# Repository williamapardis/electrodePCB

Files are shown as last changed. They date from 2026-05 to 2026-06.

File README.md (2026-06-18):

# electrodePCB
A convenient solution-circuit interface. The electrode printed circuit board (PCB) is a experimental utility with submersible application of electrochemistry in mind. The PCB is designed to fasten directly to a Blue Robotic (BR) Enclosure - [2" Cylindrical Locking Series - O-ring flanges](https://bluerobotics.com/store/watertight-enclosures/locking-series/wte-flange-vp/). The front side (or wet side) of the PCB is a layout of gold plated pads that act as substrate for unique solution processed electrode materials. The back side (or dry side) internal to the BR enclosure hosts both passive and active circuitry, their respective layout and interconnection to circuit and electrodes thought a multi. pos. FPC cable. 

<p align="center">
  
  
</p>

## rE
<p align="center">
  
  
</p>
We have upgraded to a 20 position FPC connector to accomidate more features. One these features include an additional heating element for thermal probing of the electrodes. Probing of the.

## rD
<p align="center">
  
  
</p>

## rC
<p align="center">
  
  
</p>

## rB
<p align="center">
  
  
</p>

## rA
<p align="center">
  
  
</p>

### next revision
add a convenient way to disconnect electrodes from FPC

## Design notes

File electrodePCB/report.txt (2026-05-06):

Warning: Width correction constrained.  The width correction value must be in the range of [0.000001 mm; 0.199999 mm] for the current design rules.
Plotted to '/Users/williampardis/Documents/theConductor/theConductor-F_Cu.gbr'.
Plotted to '/Users/williampardis/Documents/theConductor/theConductor-B_Cu.gbr'.
Plotted to '/Users/williampardis/Documents/theConductor/theConductor-F_Paste.gbr'.
Plotted to '/Users/williampardis/Documents/theConductor/theConductor-B_Paste.gbr'.
Plotted to '/Users/williampardis/Documents/theConductor/theConductor-F_Silkscreen.gbr'.
Plotted to '/Users/williampardis/Documents/theConductor/theConductor-B_Silkscreen.gbr'.
Plotted to '/Users/williampardis/Documents/theConductor/theConductor-F_Mask.gbr'.
Plotted to '/Users/williampardis/Documents/theConductor/theConductor-B_Mask.gbr'.
Plotted to '/Users/williampardis/Documents/theConductor/theConductor-Edge_Cuts.gbr'.
Created Gerber job file '/Users/williampardis/Documents/theConductor/theConductor-job.gbrjob'.
Plotted to '/Users/williampardis/Documents/theConductor/theConductor-F_Cu.gbr'.
Plotted to '/Users/williampardis/Documents/theConductor/theConductor-B_Cu.gbr'.
Plotted to '/Users/williampardis/Documents/theConductor/theConductor-F_Paste.gbr'.
Plotted to '/Users/williampardis/Documents/theConductor/theConductor-B_Paste.gbr'.
Plotted to '/Users/williampardis/Documents/theConductor/theConductor-F_Silkscreen.gbr'.
Plotted to '/Users/williampardis/Documents/theConductor/theConductor-B_Silkscreen.gbr'.
Plotted to '/Users/williampardis/Documents/theConductor/theConductor-F_Mask.gbr'.
Plotted to '/Users/williampardis/Documents/theConductor/theConductor-B_Mask.gbr'.
Plotted to '/Users/williampardis/Documents/theConductor/theConductor-Edge_Cuts.gbr'.
Created Gerber job file '/Users/williampardis/Documents/theConductor/theConductor-job.gbrjob'.
Info: Done.
Info: Done.

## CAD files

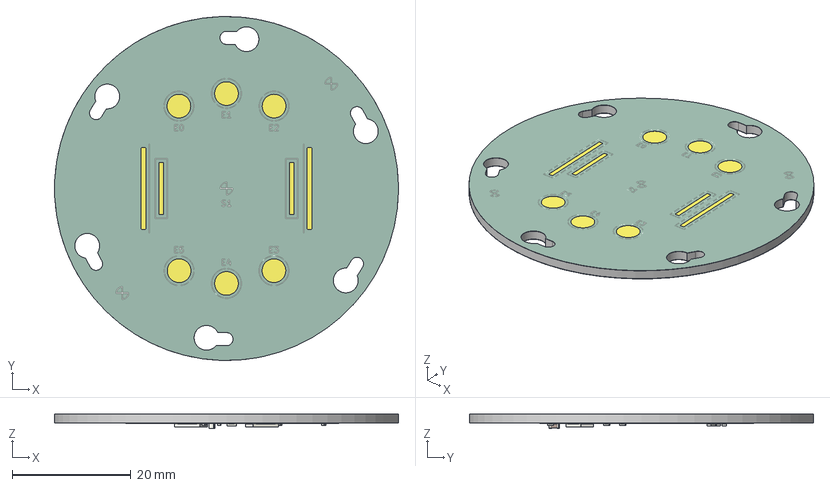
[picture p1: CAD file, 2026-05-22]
electrodePCB/electrodePCB.step
58.0 x 58.0 x 2.47 mm
R_0402_1005Metric x 4
R_0603_1608Metric x 3
R_2010_5025Metric x 2
C_0603_1608Metric
electrodePCB_copper
electrodePCB_silkscreen
electrodePCB_soldermask
electrodePCB_PCB

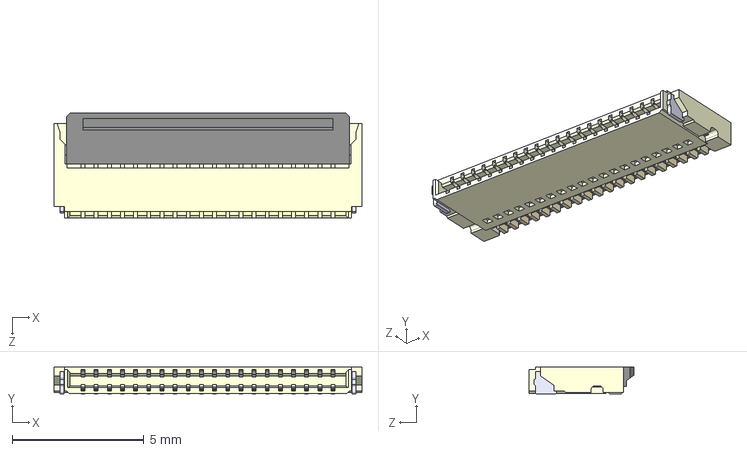
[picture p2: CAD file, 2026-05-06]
electrodePCB/FPC/5034802000.step
11.7 x 1.02 x 4.00 mm

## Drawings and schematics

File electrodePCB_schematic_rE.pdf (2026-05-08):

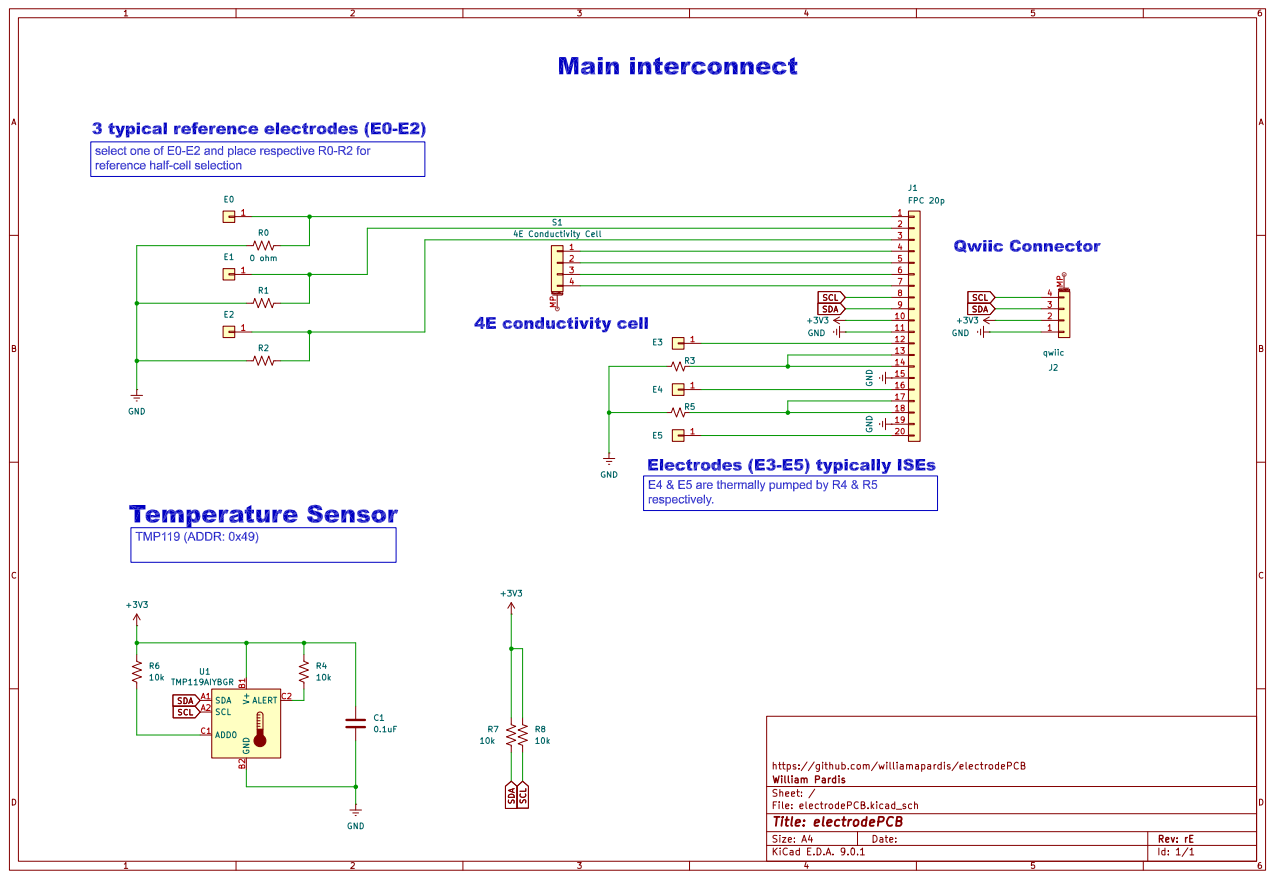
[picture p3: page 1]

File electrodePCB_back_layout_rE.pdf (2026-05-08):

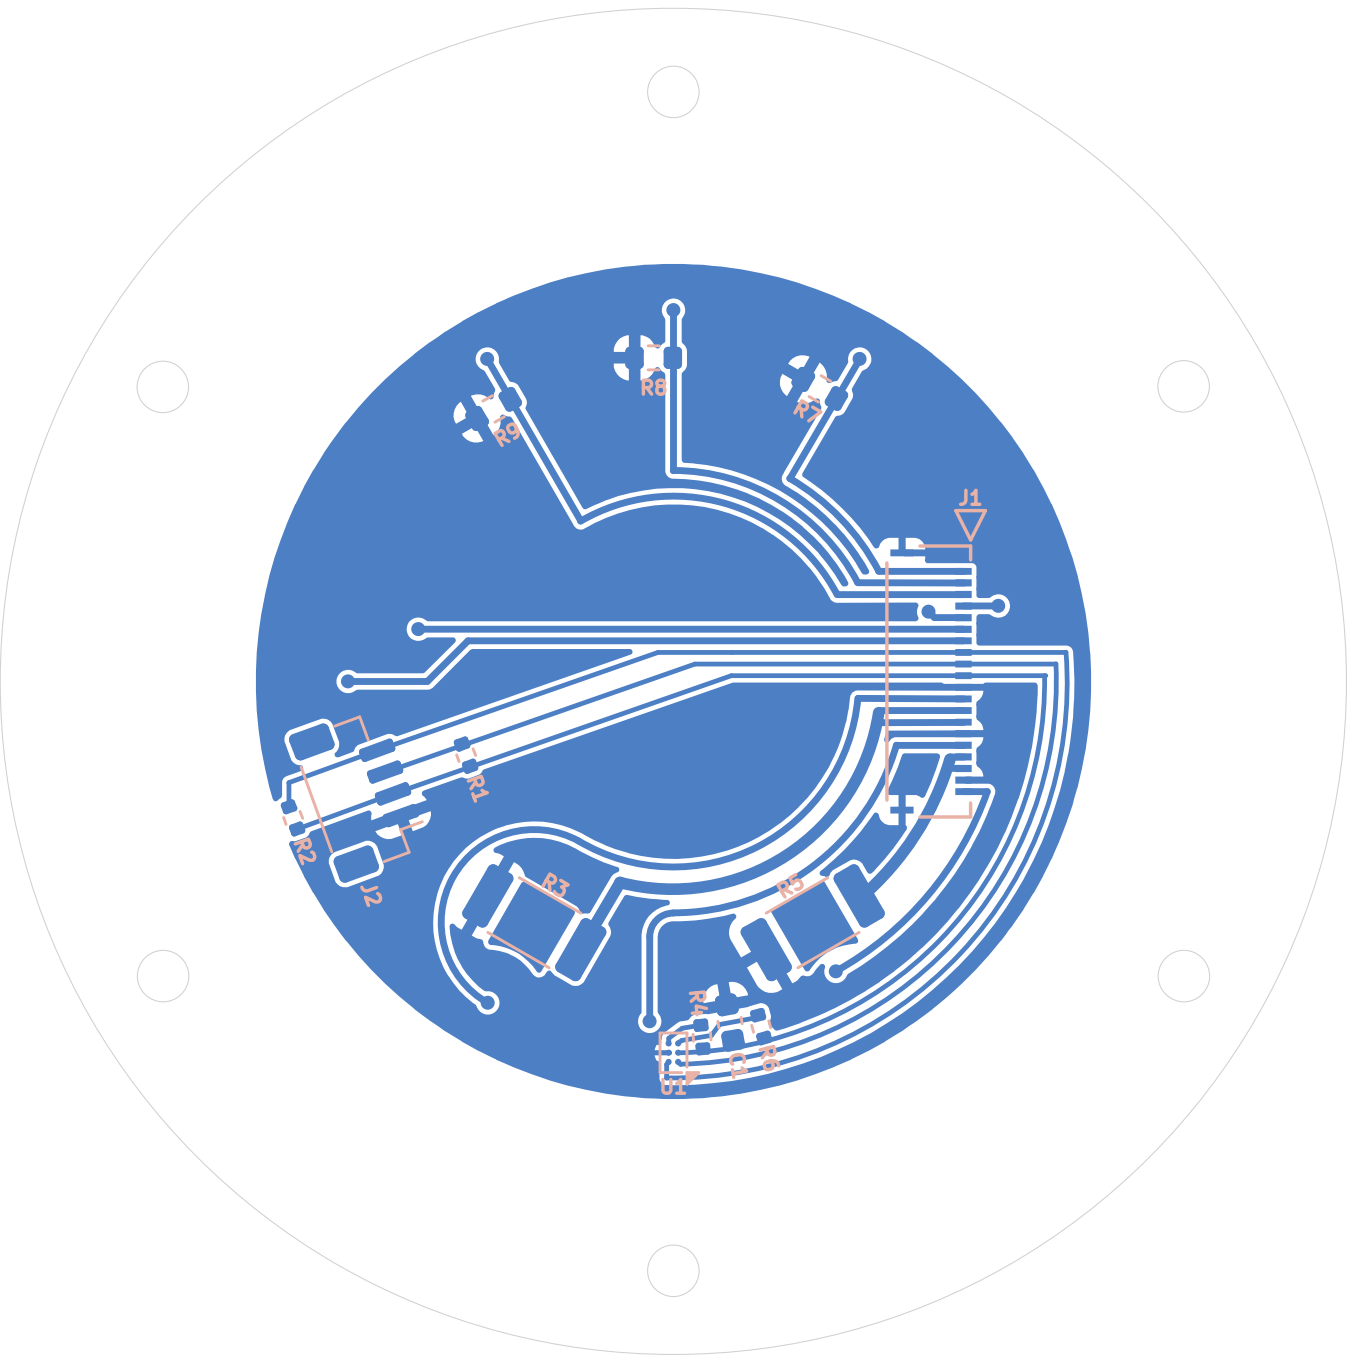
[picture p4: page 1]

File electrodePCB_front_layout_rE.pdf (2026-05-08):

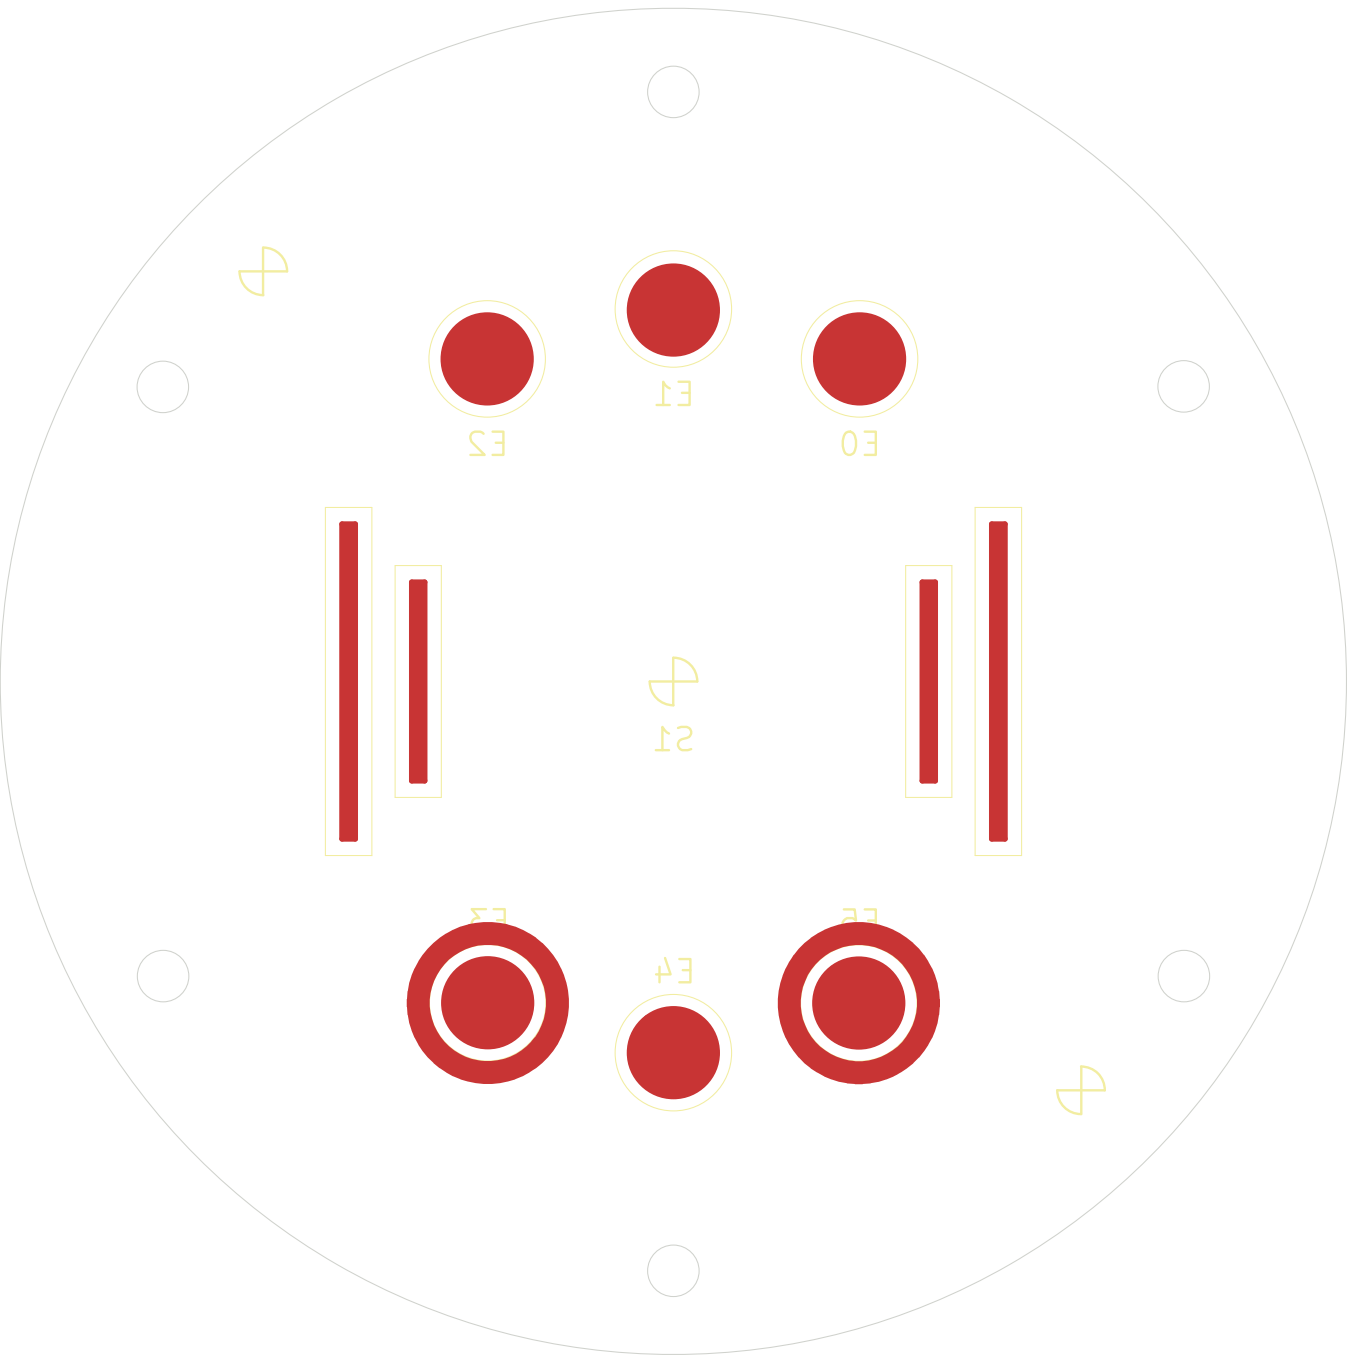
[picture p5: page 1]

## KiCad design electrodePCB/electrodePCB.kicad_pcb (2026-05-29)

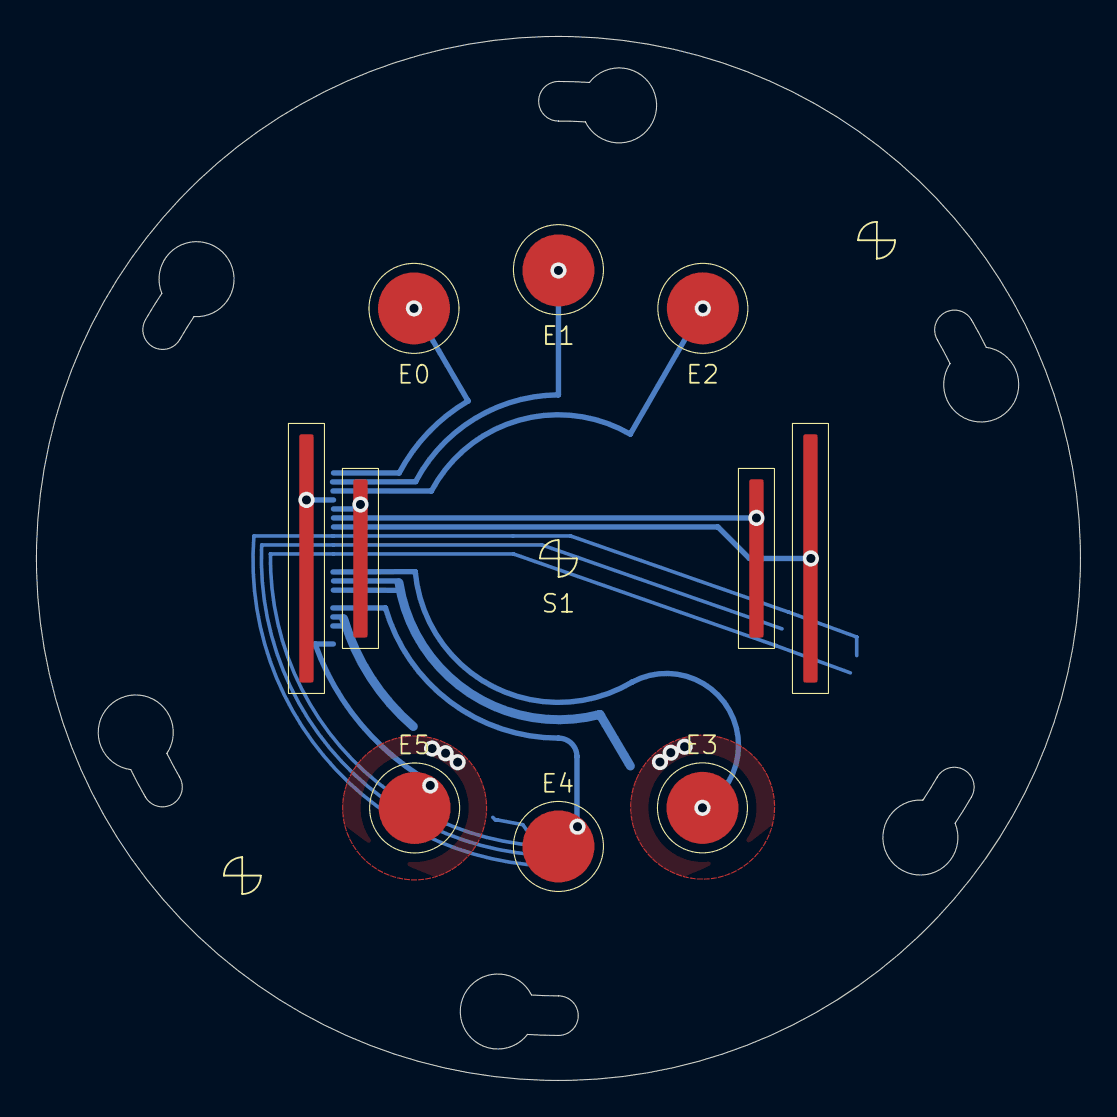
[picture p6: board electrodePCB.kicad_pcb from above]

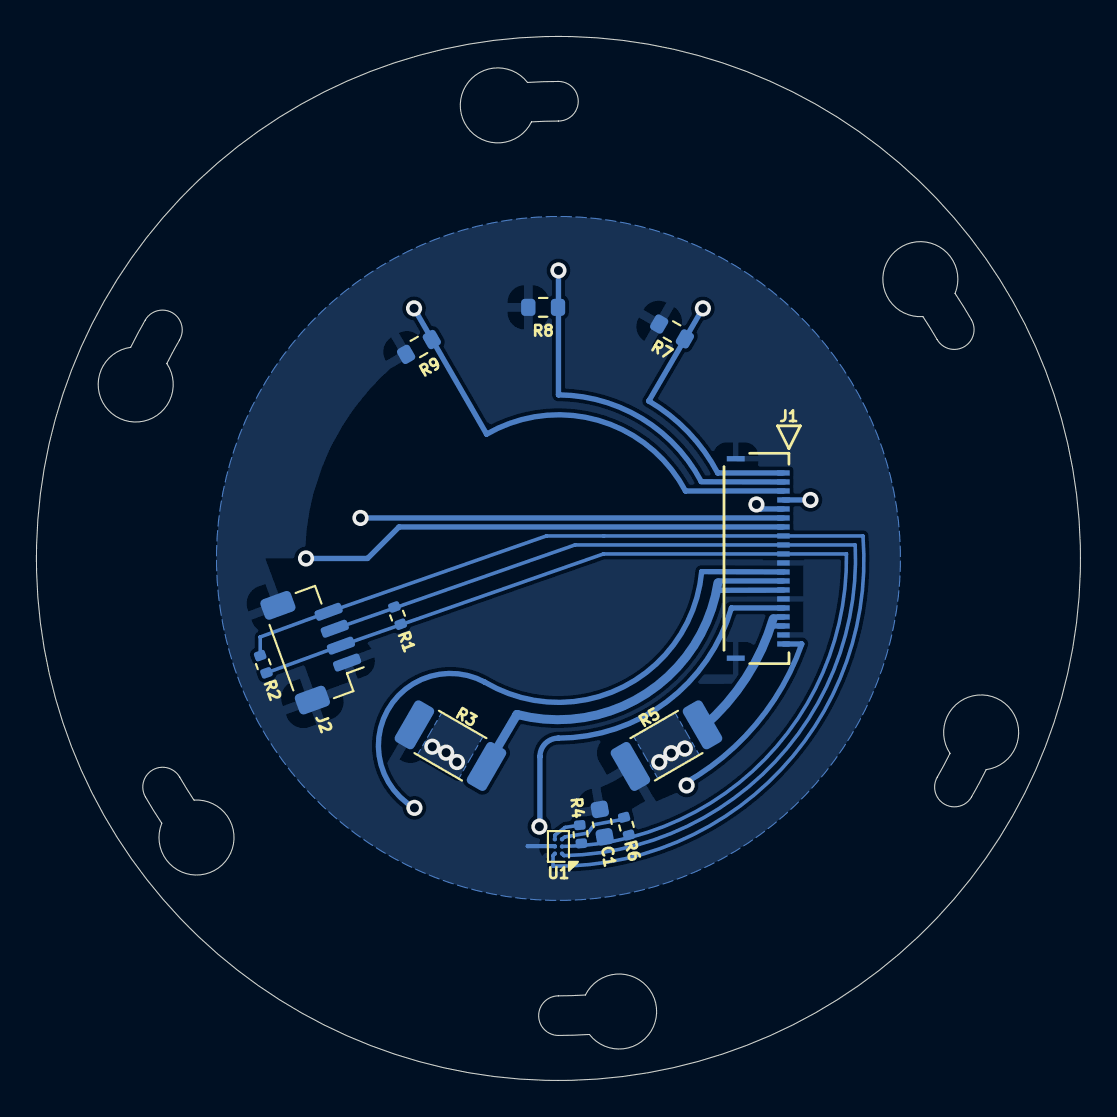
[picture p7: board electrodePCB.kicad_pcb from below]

Board: 2 copper layers, 58.0 x 58.0 mm, 20 parts (13 on the bottom side), 18 nets.

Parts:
C1: 0.1uF; C_0603_1608Metric
E0, E1, E2, E3, E4, E5: Conn_01x01; Circular_10mm
J1: FPC 20p; CON_5034802000_MOL
J2: qwiic; JST_SH_BM04B-SRSS-TB_1x04-1MP_P1.00mm_Vertical
R1, R2, R4, R6: 10k; R_0402_1005Metric
R3, R5: R_Small_US; R_2010_5025Metric
R7, R8, R9: R_US; R_0603_1608Metric
S1: 4E Conductivity Cell; Conductivity_Cell_K10
U1: TMP119AIYBGR; Texas_DSBGA-6_0.95x1.488mm_Layout2x3_P0.4mm

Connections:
+3V3: C1.1, J1.10, J2.2, R1.1, R2.2, R4.2, R6.1, U1.B1 (V+)
GND: C1.2, J1.11, J1.15, J1.19, J1.P1, J1.P2, J2.1, J2.MP (MountPin), R3.2, R5.2, R7.1, R8.1, R9.1, U1.B2 (GND)
unnamed: E0.1, J1.1, R7.2
unnamed: E1.1, J1.2, R8.2
unnamed: E2.1, J1.3, R9.2
unnamed: E3.1, J1.12
unnamed: E4.1, J1.16
unnamed: E5.1, J1.20
unnamed: J1.4, S1.1
unnamed: J1.5, S1.2
unnamed: J1.6, S1.3
unnamed: J1.7, S1.4
unnamed: J1.13, J1.14, R3.1
unnamed: J1.17, J1.18, R5.1
unnamed: R6.2, U1.C1 (ADD0)
unnamed: R4.1, U1.C2 (ALERT)
SCL: J1.8, J2.4, R2.1, U1.A2 (SCL)
SDA: J1.9, J2.3, R1.2, U1.A1 (SDA)

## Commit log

2026-05-06 adding KiCad design files and a seperate directory specifically for zip'd fab. files
    [5034802000.step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]
2026-05-06 still in the middle of it, but added the 20p, 2 additional heaters (including adjustable postition) and begining to define pinout
    [electrodePCB.kicad_pcb, electrodePCB.kicad_sch]
2026-05-07 bunch of routing, adapted interconnect pinout to accomedate routing. Added GND plane.
    [electrodePCB.kicad_pcb, electrodePCB.kicad_sch]
2026-05-08 routing, routing, routing. We removed one of the three heaters and decided to displace the other two and route to rings around the electrodes. I verified the temperature sensor is work!
    [electrodePCB.kicad_pcb, electrodePCB.kicad_sch]
2026-05-08 routing and more routing. still working, but add thermal rings. added qwiic.
    [electrodePCB.kicad_pcb, electrodePCB.kicad_sch]
2026-05-08 roughly finalized layout. Might tidy up the GND plane with some keep outs
    [electrodePCB.kicad_pcb, electrodePCB.kicad_sch]
2026-05-08 adding layout images and schematic of current design (all pdfs)
2026-05-08 added releifs for screws so we do not have to completely remove them
    [electrodePCB.kicad_pcb]
2026-05-08 cleaning up GND plane and adapted thermal pads to have larger internal radius for fab flexibility.
    [electrodePCB.kicad_pcb]
2026-05-10 GND plane triming
    [electrodePCB.kicad_pcb]
2026-05-13 labeling of the Cond Cell
    [electrodePCB.kicad_sch]
2026-05-22 generated cad file
    [electrodePCB.kicad_pcb, electrodePCB.step]
2026-05-29 added holes to mask, increased via size for epoxy fill, created fabrication files output_rE
    [electrodePCB-B_Cu.gbr, electrodePCB-B_Mask.gbr, electrodePCB-B_Paste.gbr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]
